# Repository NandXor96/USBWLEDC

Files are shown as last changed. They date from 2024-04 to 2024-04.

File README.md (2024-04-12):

# USBWLEDC
USB Sound Reactive WLED Controller

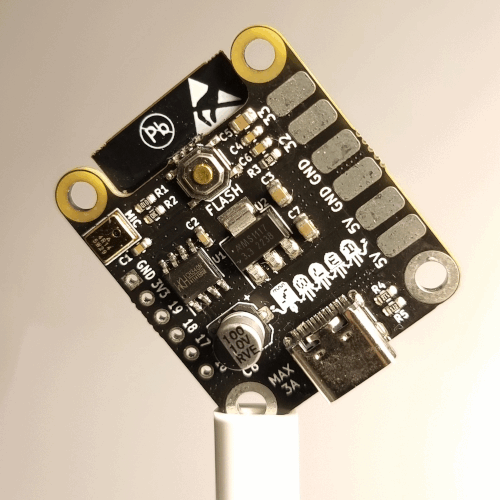
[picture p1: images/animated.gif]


## Features

- USB-C for flashing and power (max. 3A)
- Small size (30mm x 35mm)
- Cheap components
- GSA4737 MEMS Microphone (similar to SPM1423)
- Solder Pads instead of Screw Terminal Blocks
- Files for panelized version (4x4)
- Files for 3D printed case
- Front side can be populated by JLCPCB

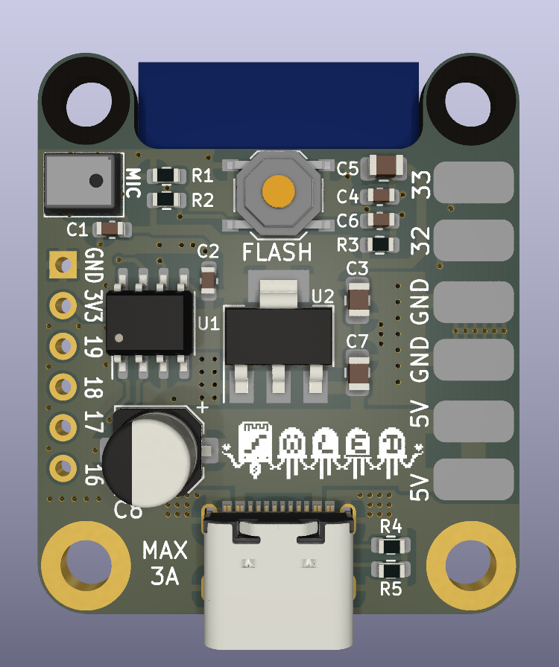
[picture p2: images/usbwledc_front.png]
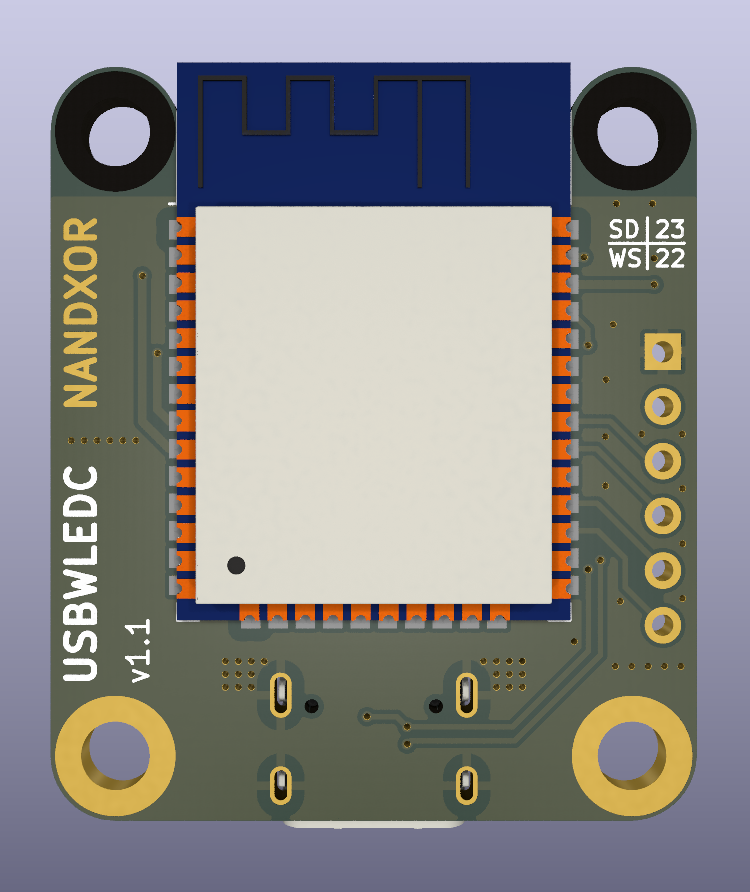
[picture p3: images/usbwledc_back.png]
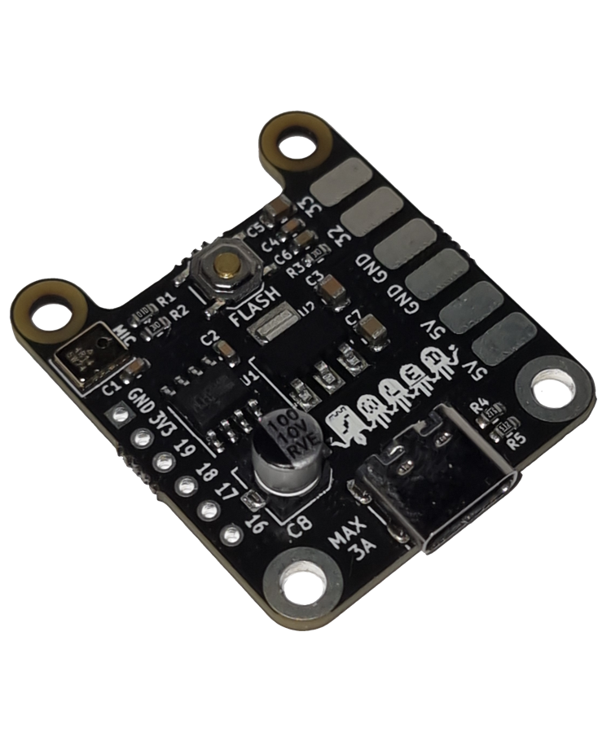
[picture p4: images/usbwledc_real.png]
 

## Case

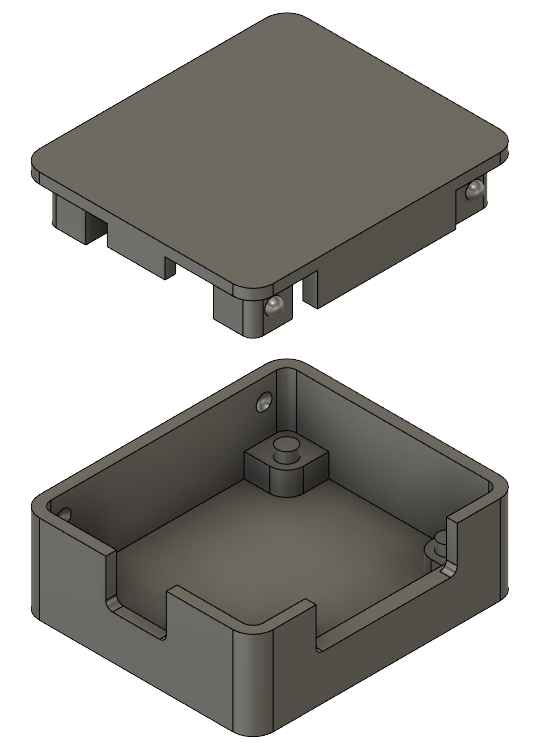
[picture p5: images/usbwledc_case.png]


## Entering Flash Mode

To enter the Flash mode of the USBWLEDC, simply hold down the button as you connect the USB cable to a computer.

## WLED Config

| Name | Value |
|---|---|
| LED Output 1: GPIO | 32 |
| LED Output 2: GPIO | 33 |
| Button 0: GPIO | 0 |
| Digitalmic: Type | Generic I2S PDM |
| Digitalmic: Pin I2S SD | GPIO 23 |
| Digitalmic: Pin I2S WS | GPIO 22 |

## BOM

|Designators |Footprint |Quantity|Value |LCSC Part #|
|---|---|---|---|---|
|C1*, C2, C4|Capacitor_SMD:C_0603_1608Metric |3 |100nF |C14663  |
|C3, C5, C7 |Capacitor_SMD:C_0805_2012Metric |3 |10uF |C15850  |
|C6 |Capacitor_SMD:C_0603_1608Metric |1 |1uF |C15849  |
|C8 |Capacitor_SMD:CP_Elec_5x5.4 |1 |100uF |C131115 |
|J10 |Connector_USB:USB_C_Receptacle_G-Switch_GT-USB-7010ASV |1 |USB-C Receptacle |C2988369|
|MK1* |Microphone:Microphone-6pin |1 |GSA4737 MEMS Microphone|C5142171|
|R1* |Resistor_SMD:R_0603_1608Metric |1 |100k |C25803  |
|R2, R3 |Resistor_SMD:R_0603_1608Metric |2 |10k |C25804  |
|R4, R5 |Resistor_SMD:R_0603_1608Metric |2 |5.1k |C23186  |
|SW1 |Button_Switch_SMD:SW_Push_1P1T_XKB_TS-1187A |1 |Push Button Flash |C318884 |
|U1 |Package_SO:SOP-8_3.9x4.9mm_P1.27mm |1 |CH340N |C2977777|
|U2 |Package_TO_SOT_SMD:SOT-223-3_TabPin2 |1 |AMS1117-3.3 |C6186 |
|U3** |RF_Module:ESP32-WROOM-32 |1 |ESP32-WROOM-32 |C701341 |

\* You can build it without the microphone. Then you don't need R1, C1 and MK1.

\*\* The ESP32-WROOM Module can be purchased at a lower cost on AliExpress.

## Assembly

When ordering from JLCPCB, you have the option to get the front side of the board pre-populated - A service I strongly endorse. Subsequently, you'll only need to solder the ESP32-WROOM module onto the reverse side. With sufficient flux, this task can be accomplished with relative ease.

For those looking to populate the whole board, I suggest using a hot plate or a reflow oven for the front side.

    Be careful to keep Isopropyl Alcohol away from the hole of the microphone when cleaning the board!

## Disclaimer

The circuit board provided on this GitHub repository is offered "as is," without any warranties or guarantees of any kind. By accessing and utilizing this circuit board, you acknowledge and agree that you do so at your own risk.

The creator and contributor of this repository, shall not be held responsible or liable for any damages, losses, or injuries that may occur as a result of building and / or using this circuit board. This includes but is not limited to any direct, indirect, consequential, or incidental damages.

Electricity is dangerous. Only attempt this project if you know what you're doing.

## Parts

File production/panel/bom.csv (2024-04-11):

Designator | Footprint | Quantity | Value | LCSC Part #
C1_4, C1_3, C1_2, C1, C2_4, C2_3, C2_2, C2, C4_4, C4_3, C4_2, C4 | 0603 | 12 | 100nF | C14663
C3_4, C3_3, C3_2, C3, C5_4, C5_3, C5_2, C5, C7_4, C7_3, C7_2, C7 | 0805 | 12 | 10uF | C15850
C6_4, C6_3, C6_2, C6 | 0603 | 4 | 1uF | C15849
C8_4, C8_3, C8_2, C8 | CP_Elec_5x5.4 | 4 | 100uF | C131115
J10_4, J10_3, J10_2, J10 | USB_C_Receptacle_G-Switch_GT-USB-7010ASV | 4 | USB_C_Receptacle_USB2.0 | C2988369
MK1_4, MK1_3, MK1_2, MK1 | Microphone-6pin | 4 | GSA4737 | C5142171
R1_4, R1_3, R1_2, R1 | 0603 | 4 | 100k | C25803
R2_4, R2_3, R2_2, R2, R3_4, R3_3, R3_2, R3 | 0603 | 8 | 10k | C25804
R4_4, R4_3, R4_2, R4, R5_4, R5_3, R5_2, R5 | 0603 | 8 | 5.1k | C23186
SW1_4, SW1_3, SW1_2, SW1 | SW_Push_1P1T_XKB_TS-1187A | 4 | FLASH_SW | C318884
U1_4, U1_3, U1_2, U1 | SOP-8_3.9x4.9mm_P1.27mm | 4 | CH340N | C2977777
U2_4, U2_3, U2_2, U2 | SOT-223-3_TabPin2 | 4 | AMS1117-3.3 | C6186

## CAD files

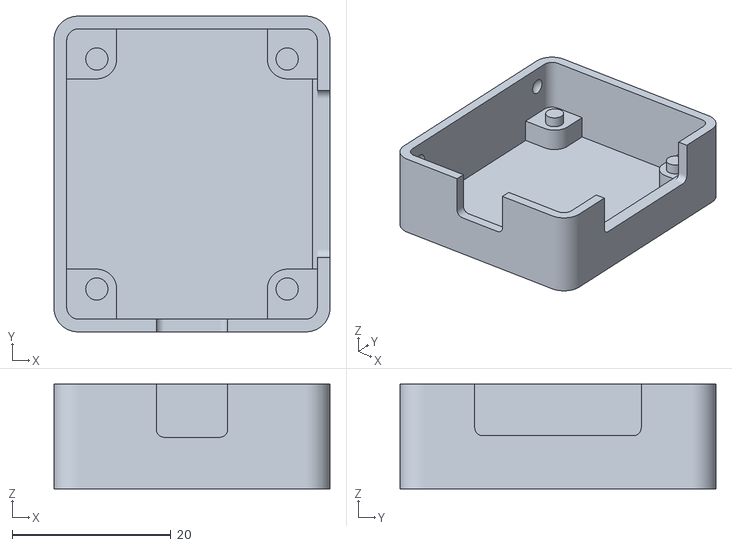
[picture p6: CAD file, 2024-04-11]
case/Base.stl
34.8 x 39.8 x 13.2

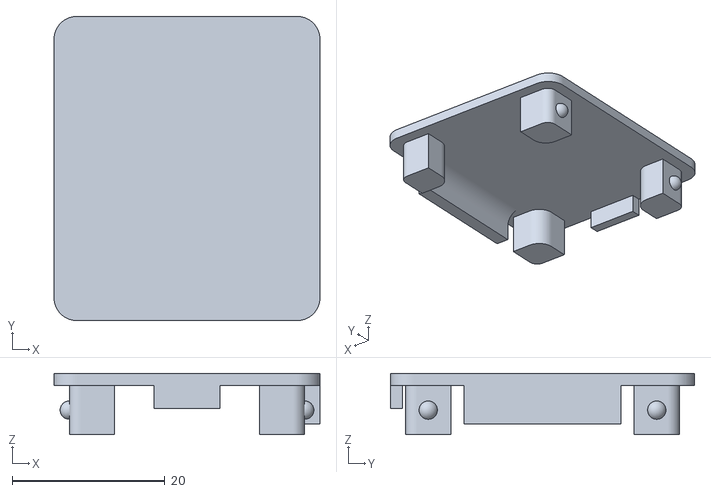
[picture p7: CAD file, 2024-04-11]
case/Top.stl
34.8 x 39.8 x 8.00

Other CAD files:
case/usbwledc-case.f3d

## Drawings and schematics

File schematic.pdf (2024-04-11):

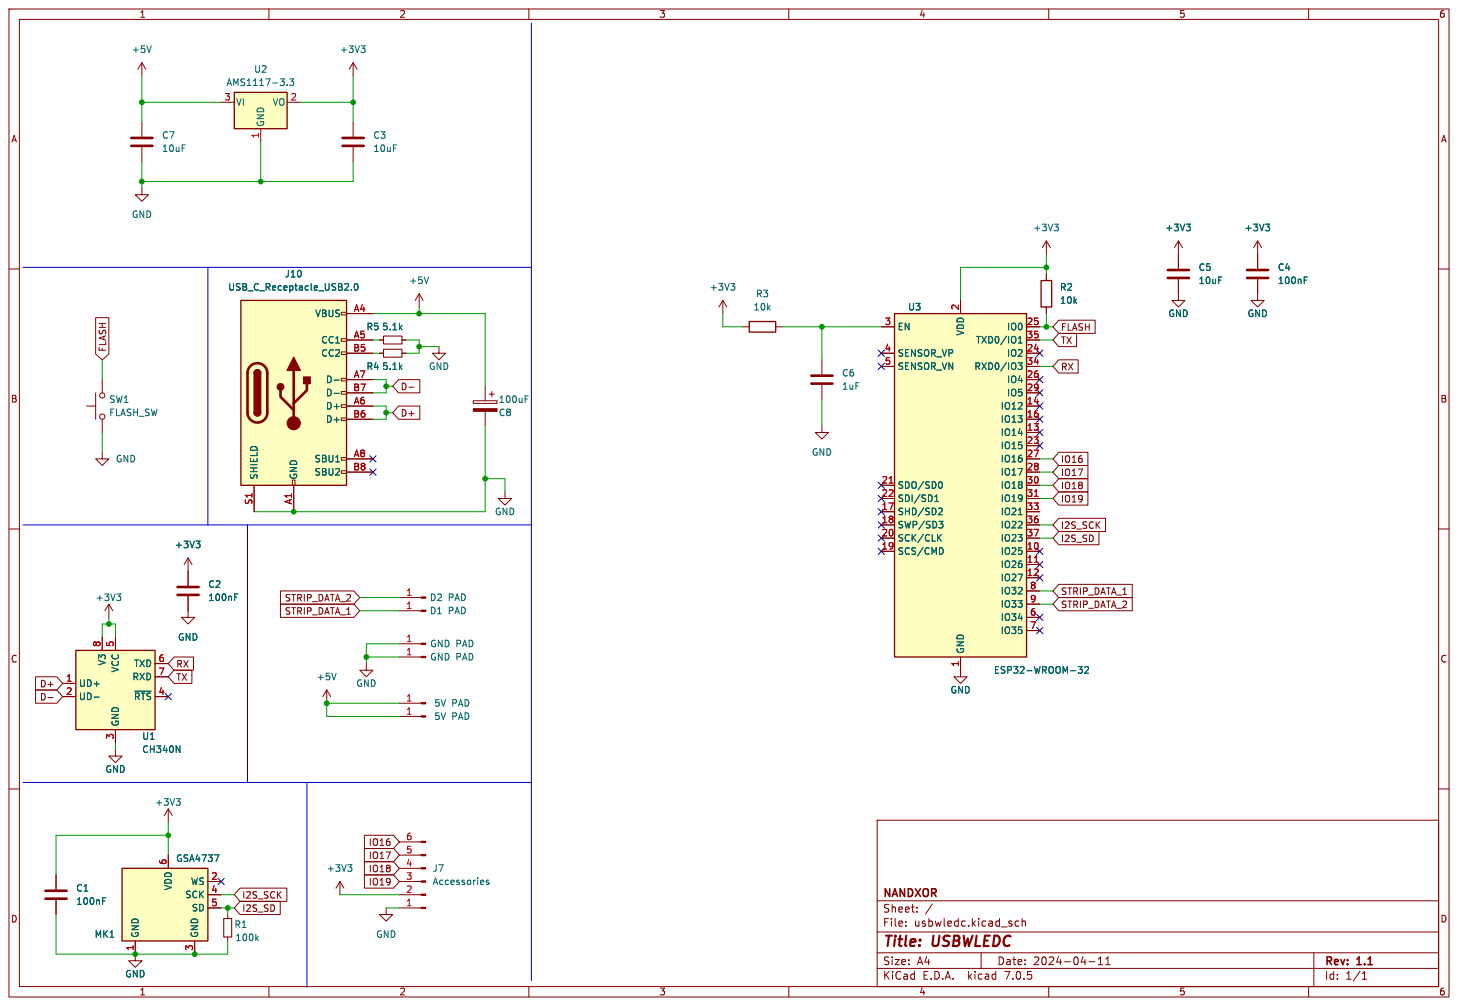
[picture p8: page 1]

File: usbwledc.kicad_sch Sheet: / NANDXOR

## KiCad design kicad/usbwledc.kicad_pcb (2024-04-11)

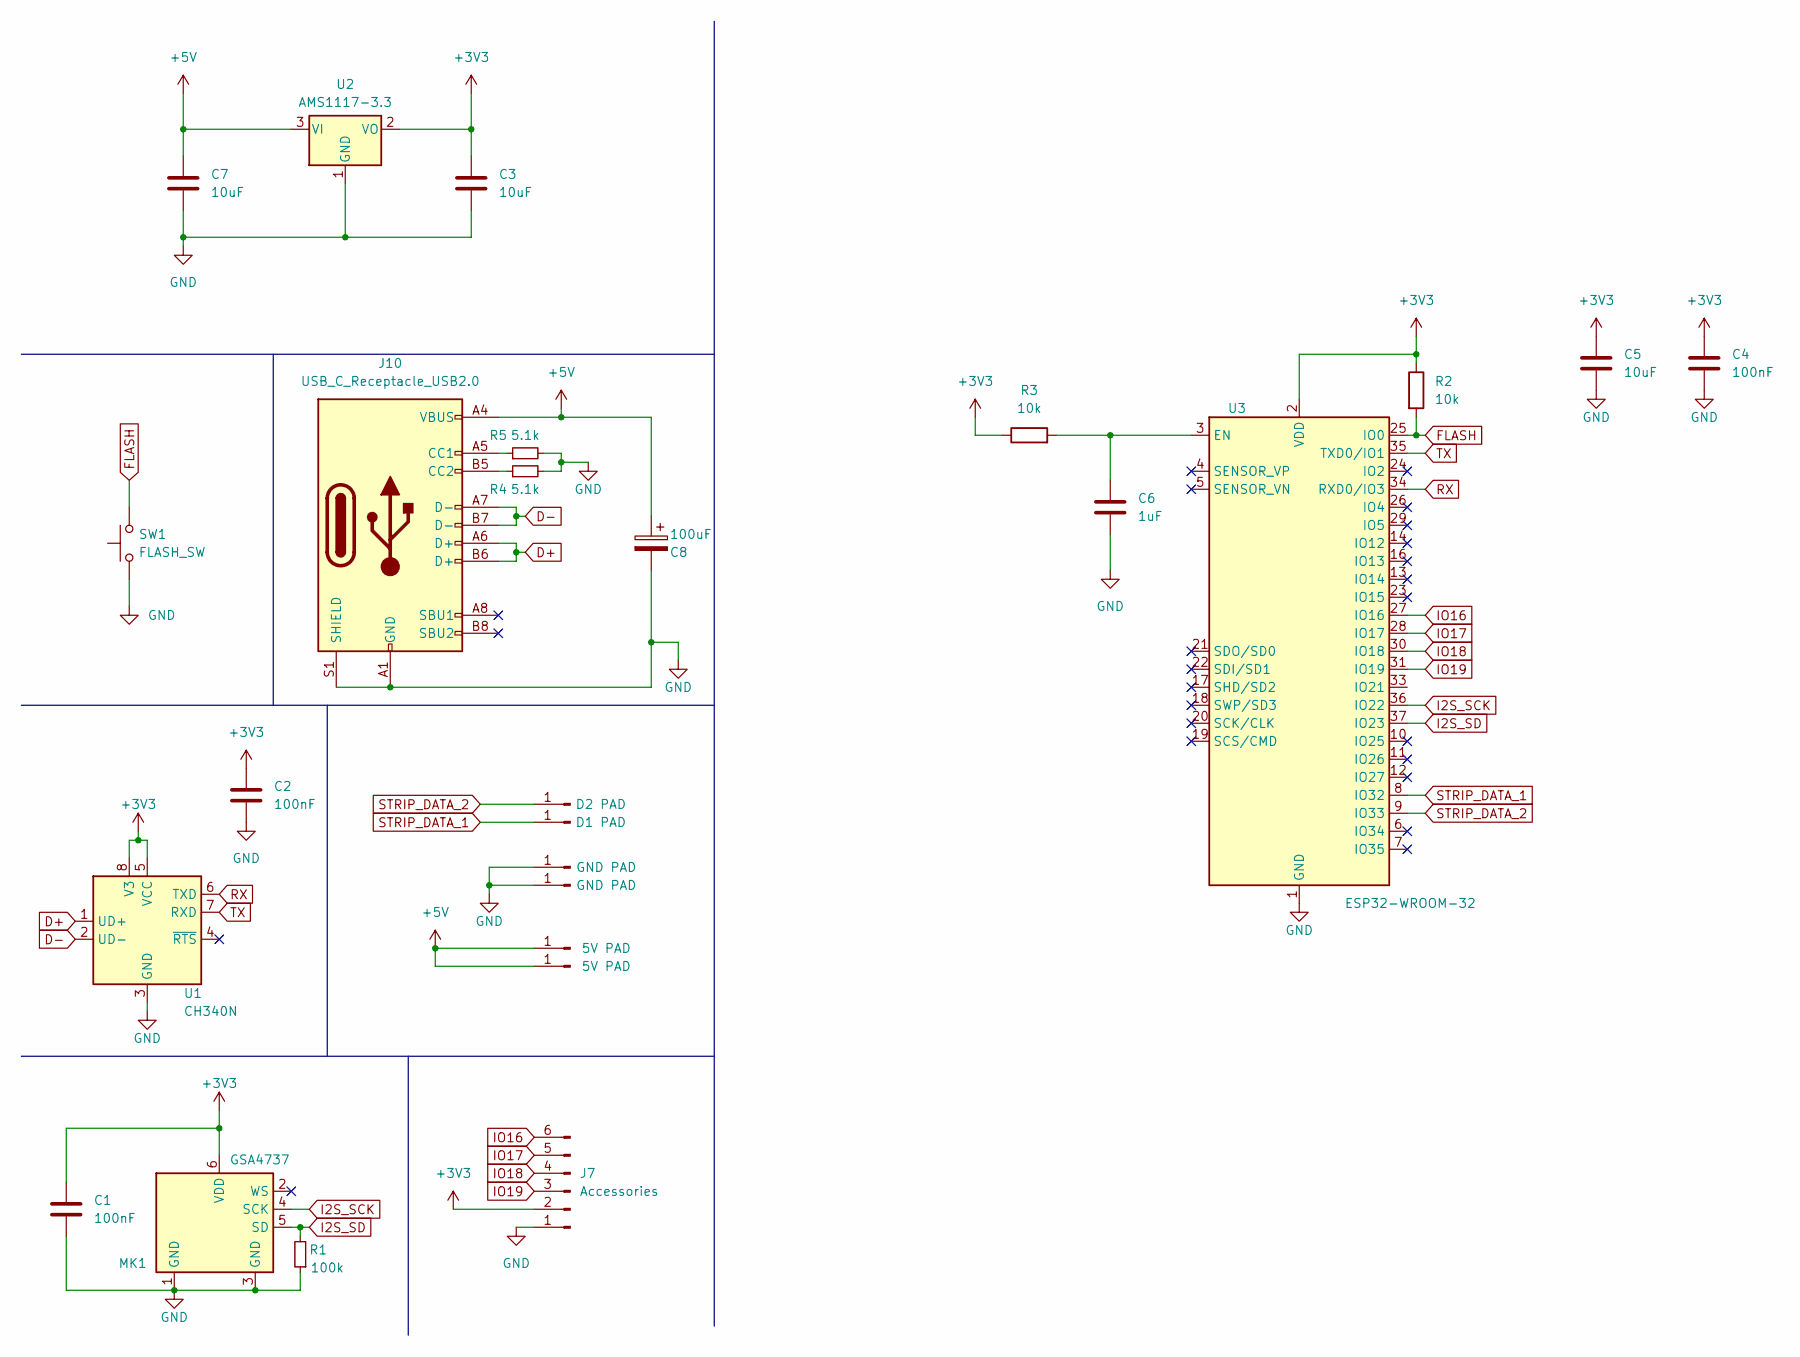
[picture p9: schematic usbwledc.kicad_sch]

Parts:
C1, C2, C4: 100nF; C_0603_1608Metric; MPN C14663
C3, C5, C7: 10uF; C_0805_2012Metric; MPN C15850
C6: 1uF; C_0603_1608Metric; MPN C15849
C8: 100uF; CP_Elec_5x5.4; MPN C131115
J1, J4: 5V PAD; SolderWirePad_1x01_SMD_3x6mm
J2: D1 PAD; SolderWirePad_1x01_SMD_3x6mm
J3, J6: GND PAD; SolderWirePad_1x01_SMD_3x6mm
J5: D2 PAD; SolderWirePad_1x01_SMD_3x6mm
J7: Accessories; PinHeader_1x06_P2.54mm_Vertical
J10: USB_C_Receptacle_USB2.0; USB_C_Receptacle_G-Switch_GT-USB-7010ASV; MPN C2988369
MK1: GSA4737; Microphone-6pin; MPN C5142171
R1: 100k; R_0603_1608Metric; MPN C25803
R2, R3: 10k; R_0603_1608Metric; MPN C25804
R4, R5: 5.1k; R_0603_1608Metric; MPN C23186
SW1: FLASH_SW; SW_Push_1P1T_XKB_TS-1187A; MPN C318884
U1: CH340N; SOP-8_3.9x4.9mm_P1.27mm; MPN C2977777
U2: AMS1117-3.3; SOT-223-3_TabPin2; MPN C6186
U3: ESP32-WROOM-32; MPN C701341; Mouser 356-ESP32WRM32E132PH

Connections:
+3V3: C1.1, C2.2, C3.1, C4.2, C5.1, J7.2, MK1.6 (VDD), R2.1, R3.1, U1.5 (VCC), U1.8 (V3), U2.2 (VO), U3.2 (VDD)
+5V: C7.1, C8.1, J1.1, J4.1, J10.A4 (VBUS), J10.A9 (VBUS), J10.B4 (VBUS), J10.B9 (VBUS), U2.3 (VI)
D+: J10.A6 (D+), J10.B6 (D+), U1.1 (UD+)
D-: J10.A7 (D-), J10.B7 (D-), U1.2 (UD-)
FLASH: R2.2, SW1.2, U3.25 (IO0)
GND: C1.2, C2.1, C3.2, C4.1, C5.2, C6.2, C7.2, C8.2, J3.1, J6.1, J7.1, J10.A1 (GND), J10.A12 (GND), J10.B1 (GND), J10.B12 (GND), J10.S1 (SHIELD), MK1.1 (GND), MK1.3 (GND), R1.1, R4.2, R5.2, SW1.1, U1.3 (GND), U2.1 (GND), U3.1 (GND), U3.15 (GND), U3.38 (GND), U3.39 (GND)
I2S_SCK: MK1.4 (SCK), U3.36 (IO22)
I2S_SD: MK1.5 (SD), R1.2, U3.37 (IO23)
IO16: J7.6, U3.27 (IO16)
IO17: J7.5, U3.28 (IO17)
IO18: J7.4, U3.30 (IO18)
IO19: J7.3, U3.31 (IO19)
unnamed: J10.A5 (CC1), R5.1
unnamed: J10.B5 (CC2), R4.1
unnamed: C6.1, R3.2, U3.3 (EN)
RELAY: U3.12 (IO27)
RX: U1.6 (TXD), U3.34 (RXD0/IO3)
STRIP_DATA_1: J2.1, U3.8 (IO32)
STRIP_DATA_2: J5.1, U3.9 (IO33)
TX: U1.7 (RXD), U3.35 (TXD0/IO1)

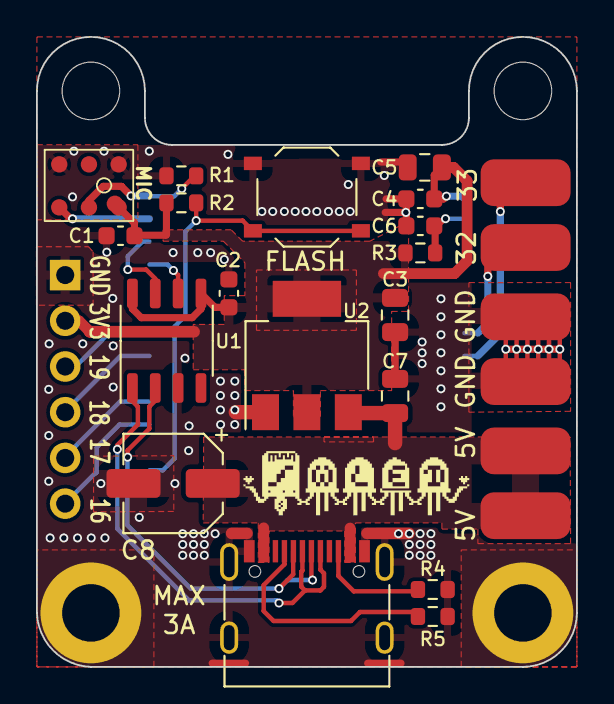
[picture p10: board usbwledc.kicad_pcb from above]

Board: 2 copper layers, 30.0 x 35.0 mm, 30 parts (1 on the bottom side), 19 nets.

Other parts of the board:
H1, H2, H3, H4: MountingHole; MountingHole_3.2mm_M3_DIN965_Pad

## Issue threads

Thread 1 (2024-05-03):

Power the board via 5V pad

renjithstalin, 2024-05-03:
Thanks for this great design..Is it possible to power the board using the 5V pads, instead of USB?

NandXor96, 2024-05-03:
Yes.
Remember to install a fuse when powering from a high current source.

renjithstalin, 2024-05-03:
Thank You so very much, also will there be a version 2.0 with more pinouts, maybe :)

Closed 2024-05-03.

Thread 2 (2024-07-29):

Alternative Mic GSA4737H12-F26-6P at JLCPCB

ChrisX1809, 2024-07-29:
Hey,

is there an alternativ way for the mic GSA4737H12-F26-6P?
I tried to order a assembled PCB at JLCPCB but the part GSA4737H12-F26-6P isn't available. Tried to order the parts at JLCPCB Service, but minimum order quantity is 2000 . Soldering this part manual seems to be difficult because of the soldering pads below.

Probably there is an alternativ component possible without adjusting the pcb layout.

I like the project and want to order an assembled PCB. So perhaps anyone has a good idea to solve.

Thx
Chris

NandXor96, 2024-07-29:
The microphone LMD4737T261-OAC02 (C19267425) should work as replacement.
However, I haven't tested it myself, so I can't guarantee its functionality. If you do try it, please share your experience with us.

Closed 2024-07-29.

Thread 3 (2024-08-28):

Missing part on jlcpcb ( 100uf cap?)

galle-led, 2024-08-28:
Gerber / BOM / CPL are uploaded successfully, everything looks good but there is this error on the Bill of Materials page:

"For below not matched parts, try our Manual Parts Selection >

Top designator:
C8_4,C8_3,C8_2,C8

Comment:
100uF

Footprint:
CP_Elec_5x5.4"

Is there something I can use in place of this?

galle-led, 2024-09-05:
https://jlcpcb.com/partdetail/KNSCHA-RST100UF10V002/C4747962

I believe i've found a suitable replacement

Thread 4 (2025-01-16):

Unable to locate Microphone (GSA4737) part or datasheet

SynchronisticSavage, 2025-01-16:
Tried uploading BOM to JLCPCB and PCBWay; both sites report they are unable to find the GSA4737 Microphone module.  upon searching the web i can not seem to find a vendor or datasheet anywhere on the net with this part number. can the SPM1423HM4H-B be used instead? does it have the same pinout and footprint? or is there another mic that can be used?

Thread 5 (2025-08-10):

AMS1117 requires tantalum capacitors

nocodeman55, 2025-08-10:
So i read the datasheet for this LDO and it states that it needs the use of tantalum capacitors.

Am i reading this wrong or are the chosen components correct replacements for tantalum capacitors?

NandXor96, 2025-08-10:
I used MLCCs because they are smaller, cheaper, and more reliable than tantalum capacitors, and in this design the LDO proved stable with them.
In my tests at different temperatures (-20 - 80 °C) and loads, the LDO with the chosen MLCCs did not oscillate. The output ripple was ok, and I also have several of these boards running without any issues.
If you are facing brownouts due to output ripple you could add an additional resistor in series to the MLCC by creating a SMD Triangle (2 smd tombstones soldered together) to increase the ESR 😄

Closed 2025-08-10.

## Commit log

2023-08-13 Small changes
    [usbwledc.kicad_pcb]
2023-08-14 Rotated Resistor Value in Schematic
    [usbwledc.kicad_sch]
